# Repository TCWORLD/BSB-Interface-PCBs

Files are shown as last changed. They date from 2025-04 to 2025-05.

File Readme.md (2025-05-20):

# Boiler System Bus (BSB) Interface PCB Designs

This repository contains a series of PCB designs used to interface between the Boiler System Bus (BSB) of certain heating systems and network interfaces.

## MCU Software

The hardware is compatible with the ESP32 software implementations from [fredlcore/BSB-LAN](https://github.com/fredlcore/BSB-LAN/). 
Note: This repo is **not affiliated** with said project in any way - support queries for these PCB designs should **not** be directed to that project.

## Hardware

The hardware is based around an ESP32 controller, with either PoE LAN or WiFi network connectivity.

The PCBs have been laid out using Eagle PCB V6.6 and use predominantly surface mount components to make machine assembly easier. Parts used are all available for assembly in JLCPCBs parts catalogue.

A library file containing all parts used is included in the repository.

CAM files are included for generating 2-Layer and 4-Layer Gerber files using a naming scheme compatible with JLCs upload.

The repository contains a ULP file that can be run to generate the CPL/BOM files for upload to JLC. 
The `LCSC_PART` and `JLC_X/Y/ROTATION` attributes have been added for each component to simplify generation of the assembly spreadsheets required by JLC. If changing the PCB designs, ensure these attributes are updated as necessary.

### BSB-to-PoELaN for DIN Mount enclosure

A full implementation including ESP32 WROOM-32UE controller, PoE Ethernet power and networking, and USB programming and SD card interfaces.

This design has been built and is fully functional. It requires the following settings in the BSB-LAN software:

* In `BSB_LAN_config.h`: Configure the following setting:
    ```
    byte bus_pins[2] = {36,4};
    ```
* In `BSB_LAN_custom_setup.h`: Add the following code:
    ```
    // Set TX Enable pin to output and set high now that the system is initialised and the
    // TX line is being driven correctly
    pinMode(32, OUTPUT);
    digitalWrite(32, HIGH);
    ```

The board and components have been designed for use with JLCPCBs economic assembly process. 

The form factor of the board has been designed to fit in a Camdenboss CNMB/3/KIT DIN mount enclosure to provide a tidy fully enclosed solution.

### BSB-to-UEXT Daughter Board *UNTESTED*

Designed to work with the ESP32-POE-ISO controller from Olimex, connecting vial the UEXT headers.

The PCB schematic is simply based on the design found at in the GitHub repository [fredlcore/BSB-LAN](https://github.com/fredlcore/BSB-LAN/tree/master/BSB_LAN/schematics).

There are some slight adaptions to provide ESD protection for the isolated B2B interface and designed to be surface-mount machine for machine assembly. 

### BSB-to-WiFi for DIN Mount enclosure *UNTESTED*

A full implementation including ESP32 WROOM-32E controller, WiFi-only networking (PCB antenna, footprint compatible with external antenna), and USB programming and SD card interfaces.
This variant omits the LAN components to reduce the number of parts and make the board cheaper to manufacture. 
Power is supplied from either a 12V screw terminal (isolated through DC/DC for safety), or powered by the USB programming port.

The board and components have been designed for use with JLCPCBs economic assembly process. 

The form factor of the board has been designed to fit in a Camdenboss CNMB/2/KIT DIN mount enclosure to provide a tidy fully enclosed solution.

---

<br />This work is licensed under a <a rel="license" href="http://creativecommons.org/licenses/by-nc-sa/4.0/">Creative Commons Attribution-NonCommercial-ShareAlike 4.0 International License</a>.

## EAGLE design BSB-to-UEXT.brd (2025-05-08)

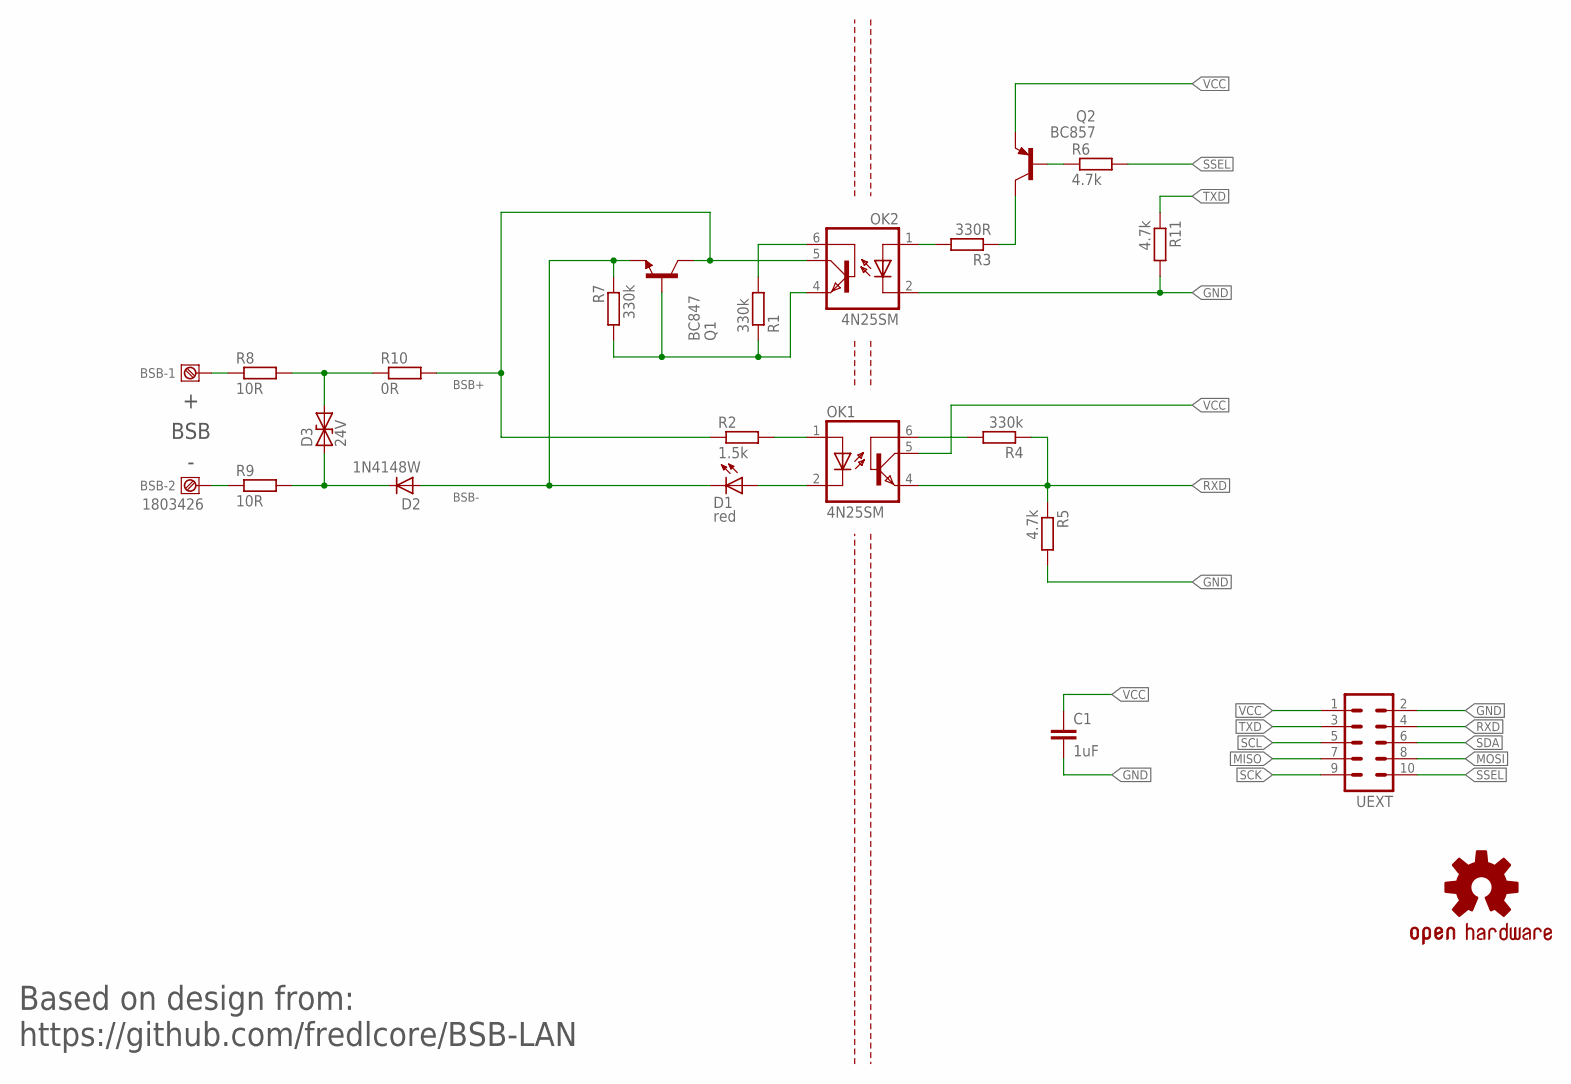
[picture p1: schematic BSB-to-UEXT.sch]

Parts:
BSB: 1803426; LCSC_PART C480514
C1: 1uF; C0805; LCSC_PART C28323
D1: red; CHIPLED_0805; LCSC_PART C84256
D2: 1N4148W; SOD123; LCSC_PART C81598
D3: 24V; SMBG; LCSC_PART C83268
OK1, OK2: 4N25SM; DIL6-SMD; LCSC_PART C258246
Q1: BC847; SOT23; LCSC_PART C130417
Q2: BC857; SOT23-BEC; LCSC_PART C426782
R1, R4, R7: 330k; R0805; LCSC_PART C17629
R2: 1.5k; R0805; LCSC_PART C4310
R3: 330R; R0805; LCSC_PART C17630
R5, R6, R11: 4.7k; R0805; LCSC_PART C17673
R8, R9: 10R; R1206; LCSC_PART C17903
R10: 0R; R1206L; LCSC_PART C17888
U$3: DNI; OSHW-LOGO-M
UEXT: ML10F

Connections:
BSB+: OK2.5 (COL), Q1.3 (C), R2.1, R10.2
BSB-: D1.C, D2.A, Q1.2 (E), R7.1
BSB-RX-A: OK1.1 (A), R2.2
BSB-RX-K: D1.A, OK1.2 (C)
BSB-TX-B: OK2.6 (BAS), R1.2
BSB-TX-E: OK2.4 (EMI), Q1.1 (B), R1.1, R7.2
CON-BSB+: BSB.1, R8.1
CON-BSB-: BSB.2, R9.1
GND: C1.2, OK2.2 (C), R5.2, R11.2, UEXT.2
MISO: UEXT.7
MOSI: UEXT.8
RXD: OK1.4 (EMI), R4.1, R5.1, UEXT.4
RXD-B: OK1.6 (BAS), R4.2
SCK: UEXT.9
SCL: UEXT.5
SDA: UEXT.6
SSEL: R6.2, UEXT.10
TVS-BSB+: D3.2, R8.2, R10.1
TVS-BSB-: D2.C, D3.1, R9.2
TXD: R11.1, UEXT.3
TXD-A: OK2.1 (A), R3.2
TXD-B: Q2.B, R6.1
TXD-C: Q2.C, R3.1
VCC: C1.1, OK1.5 (COL), Q2.E, UEXT.1

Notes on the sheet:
+ BSB -
Based on design from: https://github.com/fredlcore/BSB-LAN

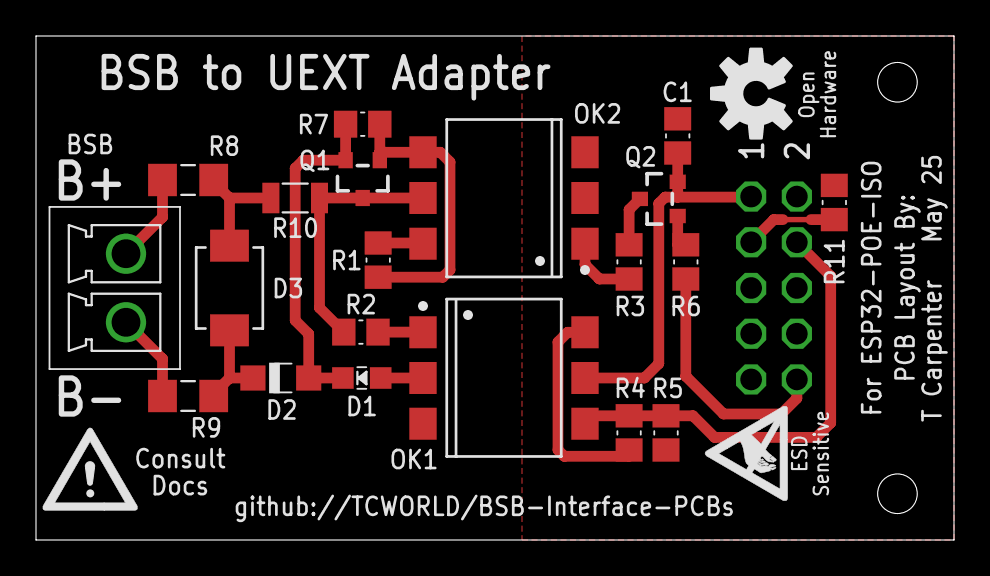
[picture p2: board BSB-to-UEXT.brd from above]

Board: 2 copper layers, 51.0 x 28.0 mm, 24 parts (1 on the bottom side), 19 nets.

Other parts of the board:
U$1: WARN-TINY
U$2: ESD-TINY

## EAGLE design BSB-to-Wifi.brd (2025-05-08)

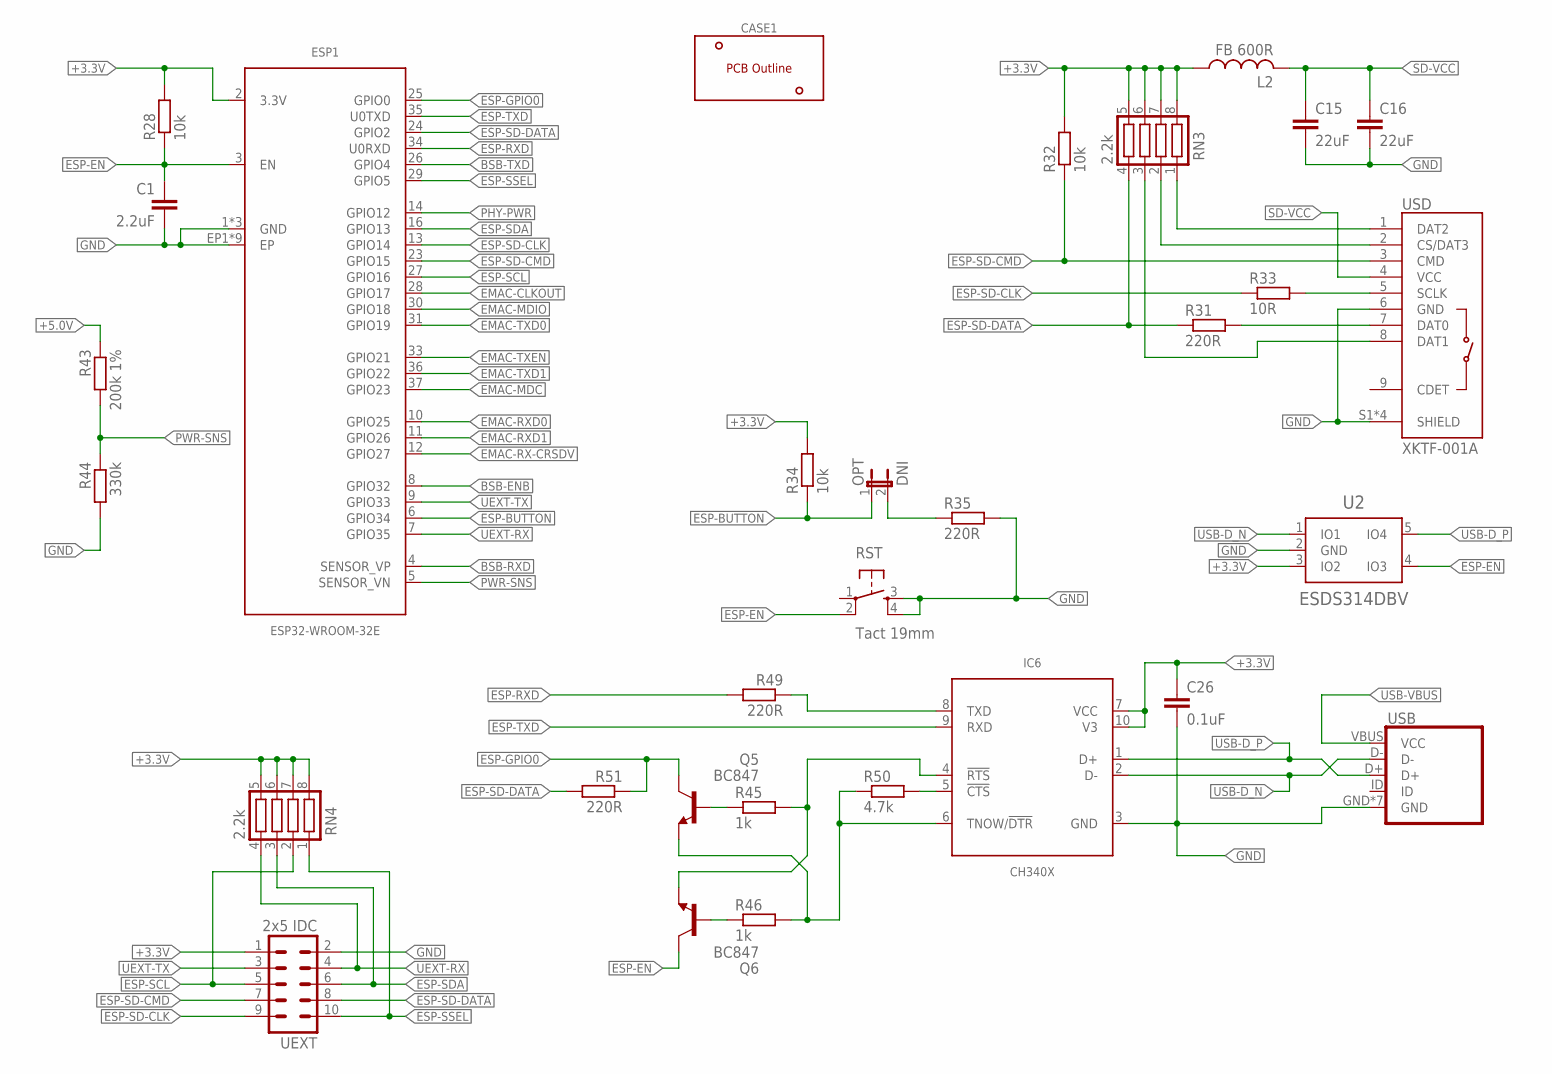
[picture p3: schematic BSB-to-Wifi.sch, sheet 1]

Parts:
C1: 2.2uF; C0603; LCSC_PART C23630
C15, C16: 22uF; C0805L; LCSC_PART C45783
C26: 0.1uF; C0402; LCSC_PART C1525
CASE1: DNI; CNMB/2-
ESP1: ESP32-WROOM-32E
IC6: CH340X; MSOP10
L2: FB 600R; L2010; LCSC_PART C1017
OPT: DNI; 1X02
Q5: BC847; SOT23; LCSC_PART C130417
Q6: BC847; SOT23
R28, R32, R34: 10k; R0402; LCSC_PART C25744
R31, R35, R49, R51: 220R; R0402; LCSC_PART C25091
R33: 10R; R0603L; LCSC_PART C22859
R43: 200k 1%; R0402; LCSC_PART C25764
R44: 330k; R0603L; LCSC_PART C23137
R45, R46: 1k; R0402; LCSC_PART C11702
R50: 4.7k; R0402; LCSC_PART C25900
RN3, RN4: 2.2k; CTS742C083; LCSC_PART C414564
RST: Tact 19mm; TACTILE_SWITCH; LCSC_PART C2837529
U2: ESDS314DBV; DBV0005A-SOT23
UEXT: 2x5 IDC; ML10
USB: ZX62-B-5PA(33); USB-MICROB
USD: XKTF-001A; MICRO-SD

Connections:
+3.3V: C26.1, ESP1.2 (3.3V), IC6.7 (VCC), IC6.10 (V3), L2.1, R28.2, R32.2, R34.2, RN3.5, RN3.6, RN3.7, RN3.8, RN4.5, RN4.6, RN4.7, RN4.8, U2.3 (IO2), UEXT.1; also elsewhere on the board
+5.0V: R43.1; also elsewhere on the board
BSB-ENB: ESP1.8 (GPIO32); also elsewhere on the board
BSB-RXD: ESP1.4 (SENSOR_VP); also elsewhere on the board
BSB-TXD: ESP1.26 (GPIO4); also elsewhere on the board
CH340-!CTS: IC6.5 (!CTS), R50.2
CH340-!DTR: IC6.6 (TNOW/!DTR), Q5.2 (E), R46.2, R50.1
CH340-!RTS: IC6.4 (!RTS), Q6.2 (E), R45.2
CH340-TXD: IC6.8 (TXD), R49.1
EMAC-CLKOUT: ESP1.28 (GPIO17)
EMAC-MDC: ESP1.37 (GPIO23)
EMAC-MDIO: ESP1.30 (GPIO18)
EMAC-RX-CRSDV: ESP1.12 (GPIO27)
EMAC-RXD0: ESP1.10 (GPIO25)
EMAC-RXD1: ESP1.11 (GPIO26)
EMAC-TXD0: ESP1.31 (GPIO19)
EMAC-TXD1: ESP1.36 (GPIO22)
EMAC-TXEN: ESP1.33 (GPIO21)
ESP-BUTTON: ESP1.6 (GPIO34), OPT.1, R34.1
ESP-BUTTON-R: OPT.2, R35.1
ESP-EN: C1.1, ESP1.3 (EN), Q6.3 (C), R28.1, RST.2, U2.4 (IO3)
ESP-EN-OE: Q6.1 (B), R46.1
ESP-GPIO0: ESP1.25 (GPIO0), Q5.3 (C), R51.1
ESP-GPIO0-OE: Q5.1 (B), R45.1
ESP-RXD: ESP1.34 (U0RXD), R49.2
ESP-SCL: ESP1.27 (GPIO16), RN4.2, UEXT.5
ESP-SD-CLK: ESP1.13 (GPIO14), R33.1, UEXT.9
ESP-SD-CMD: ESP1.23 (GPIO15), R32.1, UEXT.7, USD.3 (CMD)
ESP-SD-DATA: ESP1.24 (GPIO2), R31.1, R51.2, RN3.4, UEXT.8
ESP-SDA: ESP1.16 (GPIO13), RN4.3, UEXT.6
ESP-SSEL: ESP1.29 (GPIO5), RN4.1, UEXT.10
ESP-TXD: ESP1.35 (U0TXD), IC6.9 (RXD)
GND: C1.2, C15.2, C16.2, C26.2, ESP1.1 (GND), ESP1.15 (GND), ESP1.38 (GND), ESP1.EP1 (EP), ESP1.EP2 (EP), ESP1.EP3 (EP), ESP1.EP4 (EP), ESP1.EP5 (EP), ESP1.EP6 (EP), ESP1.EP7 (EP), ESP1.EP8 (EP), ESP1.EP9 (EP), IC6.3 (GND), R35.2, R44.2, RST.3, RST.4, U2.2 (GND), UEXT.2, USB.GND, USB.MT1 (GND), USB.MT2 (GND), USB.MT3 (GND), USB.MT4 (GND), USB.MT5 (GND), USB.MT6 (GND), USD.6 (GND), USD.S1 (SHIELD), USD.S2 (SHIELD), USD.S3 (SHIELD), USD.S4 (SHIELD); also elsewhere on the board
PHY-PWR: ESP1.14 (GPIO12)
PWR-SNS: ESP1.5 (SENSOR_VN), R43.2, R44.1
SD-DAT0: R31.2, USD.7 (DAT0)
SD-DAT1: RN3.3, USD.8 (DAT1)
SD-DAT2: RN3.1, USD.1 (DAT2)
SD-DAT3: RN3.2, USD.2 (CS/DAT3)
SD-SCLK: R33.2, USD.5 (SCLK)
SD-VCC: C15.1, C16.1, L2.2, USD.4 (VCC)
UEXT-RX: ESP1.7 (GPIO35), RN4.4, UEXT.4
UEXT-TX: ESP1.9 (GPIO33), UEXT.3
USB-D_N: IC6.2 (D-), U2.1 (IO1), USB.D-
USB-D_P: IC6.1 (D+), U2.5 (IO4), USB.D+
USB-VBUS: USB.VBUS (VCC); also elsewhere on the board

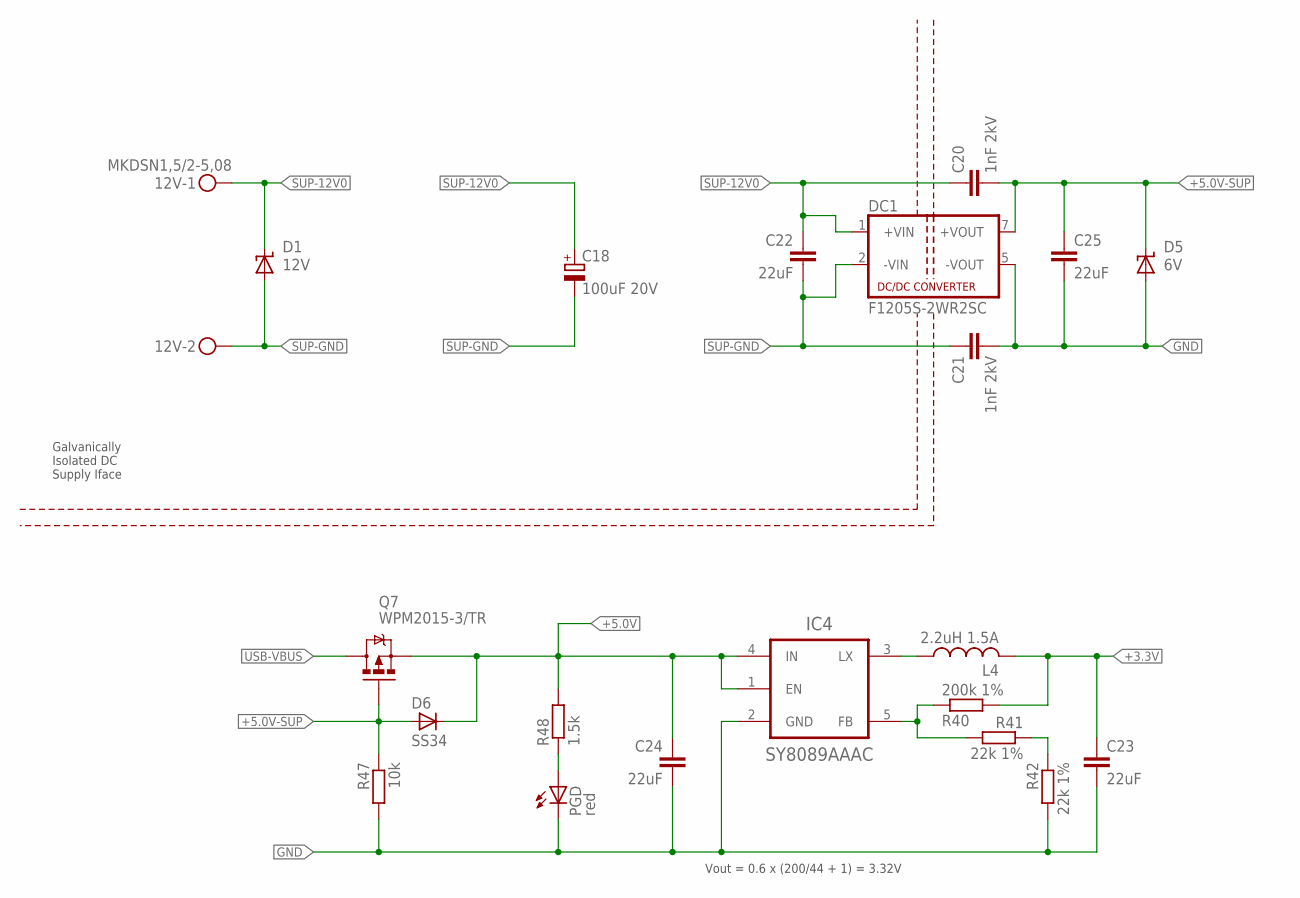
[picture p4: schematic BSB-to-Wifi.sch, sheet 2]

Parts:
12V: MKDSN1,5/2-5,08; MKDSN1_5-2-5_08
C18: 100uF 20V; SMC_D; LCSC_PART C7224
C20, C21: 1nF 2kV; C1206L; LCSC_PART C9196
C22, C23, C24, C25: 22uF; C0805; LCSC_PART C45783
D1: 12V; SMA; LCSC_PART C148213
D5: 6V; SMA; LCSC_PART C223993
D6: SS34; SMA; LCSC_PART C8678
DC1: F1205S-2WR2SC; SIP7-N
IC4: SY8089AAAC; DBV0005A-SOT23
L4: 2.2uH 1.5A; L4040P; LCSC_PART C135262
PGD: red; CHIP-LED0603; LCSC_PART C2286
Q7: WPM2015-3/TR; SOT23
R40: 200k 1%; R0402; LCSC_PART C25764
R41, R42: 22k 1%; R0402; LCSC_PART C25768
R47: 10k; R0402; LCSC_PART C25744
R48: 1.5k; R0603; LCSC_PART C22843

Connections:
3V3-FB: IC4.5 (FB), R40.1, R41.2
3V3-FB-RB: R41.1, R42.1
3V3-LX: IC4.3 (LX), L4.1
+3.3V: C23.1, L4.2, R40.2; also elsewhere on the board
+5.0V: C24.1, D6.C, IC4.1 (EN), IC4.4 (IN), Q7.2 (S), R48.2; also elsewhere on the board
+5.0V-SUP: C20.2, C25.1, D5.C, D6.A, DC1.7 (+VOUT), Q7.1 (G), R47.1
GND: C21.2, C23.2, C24.2, C25.2, D5.A, DC1.5 (-VOUT), IC4.2 (GND), PGD.C, R42.2, R47.2; also elsewhere on the board
PWR-LED: PGD.A, R48.1
SUP-12V0: 12V.1, C18.+, C20.1, C22.1, D1.C, DC1.1 (+VIN)
SUP-GND: 12V.2, C18.-, C21.1, C22.2, D1.A, DC1.2 (-VIN)
USB-VBUS: Q7.3 (D); also elsewhere on the board

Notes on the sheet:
Galvanically Isolated DC Supply Iface
Vout = 0.6 x (200/44 + 1) = 3.32V

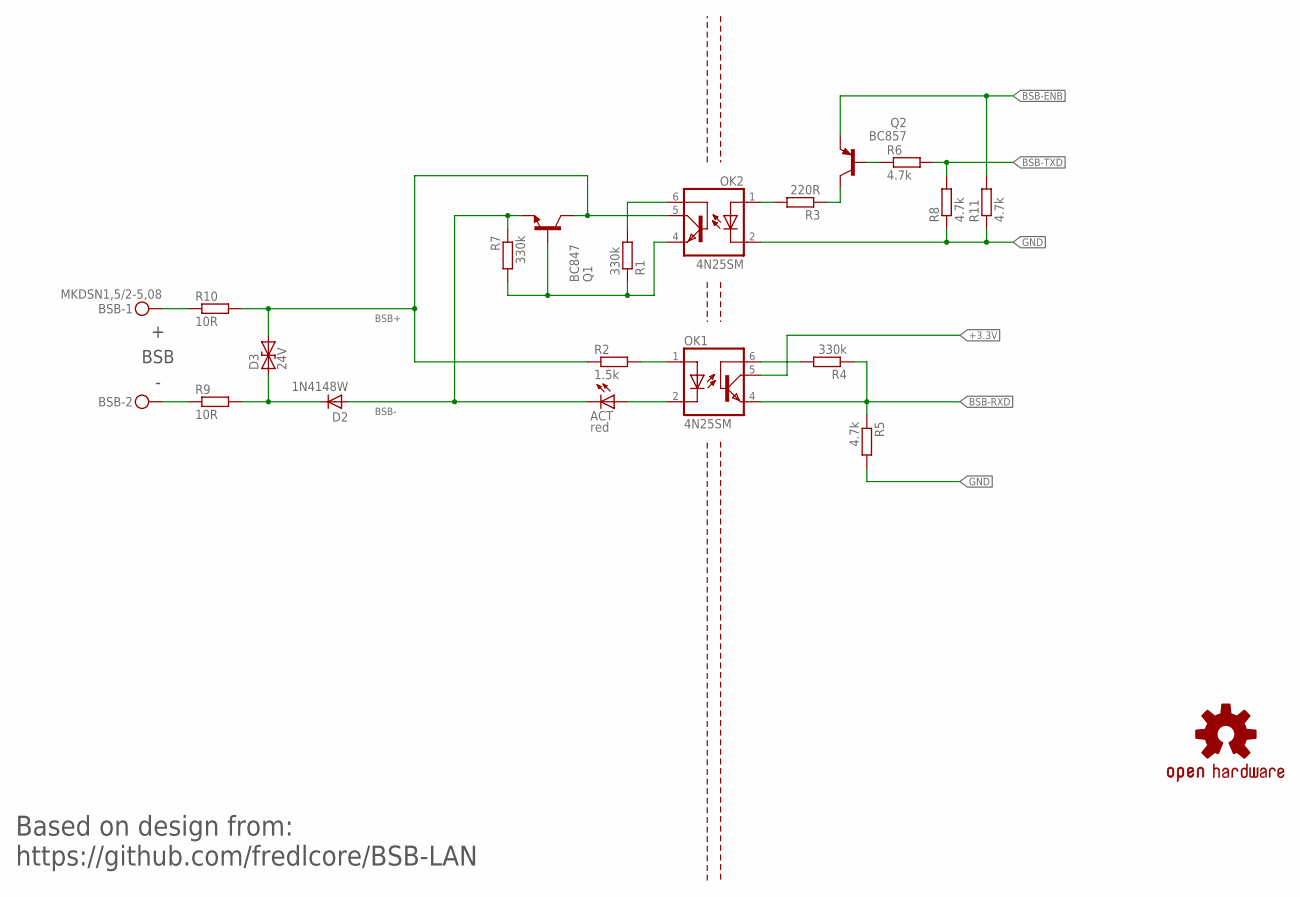
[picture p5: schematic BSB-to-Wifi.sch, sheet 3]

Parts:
ACT: red; CHIP-LED0603; LCSC_PART C2286
BSB: MKDSN1,5/2-5,08; MKDSN1_5-2-5_08
D2: 1N4148W; SOD123; LCSC_PART C81598
D3: 24V; SMBG; LCSC_PART C83268
OK1, OK2: 4N25SM; DIL6-SMD; LCSC_PART C258246
Q1: BC847; SOT23; LCSC_PART C130417
Q2: BC857; SOT23-BEC; LCSC_PART C426782
R1, R4, R7: 330k; R0603; LCSC_PART C23137
R2: 1.5k; R0603; LCSC_PART C22843
R3: 220R; R0402; LCSC_PART C25091
R5, R6, R8, R11: 4.7k; R0402; LCSC_PART C25900
R9, R10: 10R; R0603; LCSC_PART C22859
U$3: DNI; OSHW-LOGO-M

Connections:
+3.3V: OK1.5 (COL); also elsewhere on the board
BSB+: D3.2, OK2.5 (COL), Q1.3 (C), R2.1, R10.2
BSB-: ACT.C, D2.A, Q1.2 (E), R7.1
BSB-ENB: Q2.E, R11.2; also elsewhere on the board
BSB-RX-A: OK1.1 (A), R2.2
BSB-RX-K: ACT.A, OK1.2 (C)
BSB-RXD: OK1.4 (EMI), R4.1, R5.1; also elsewhere on the board
BSB-TX-B: OK2.6 (BAS), R1.2
BSB-TX-E: OK2.4 (EMI), Q1.1 (B), R1.1, R7.2
BSB-TXD: R6.2, R8.2; also elsewhere on the board
CON-BSB+: BSB.1, R10.1
CON-BSB-: BSB.2, R9.1
GND: OK2.2 (C), R5.2, R8.1, R11.1; also elsewhere on the board
RXD-B: OK1.6 (BAS), R4.2
TVS-BSB-: D2.C, D3.1, R9.2
TXD-A: OK2.1 (A), R3.2
TXD-B: Q2.B, R6.1
TXD-C: Q2.C, R3.1

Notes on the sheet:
+ BSB -
Based on design from: https://github.com/fredlcore/BSB-LAN

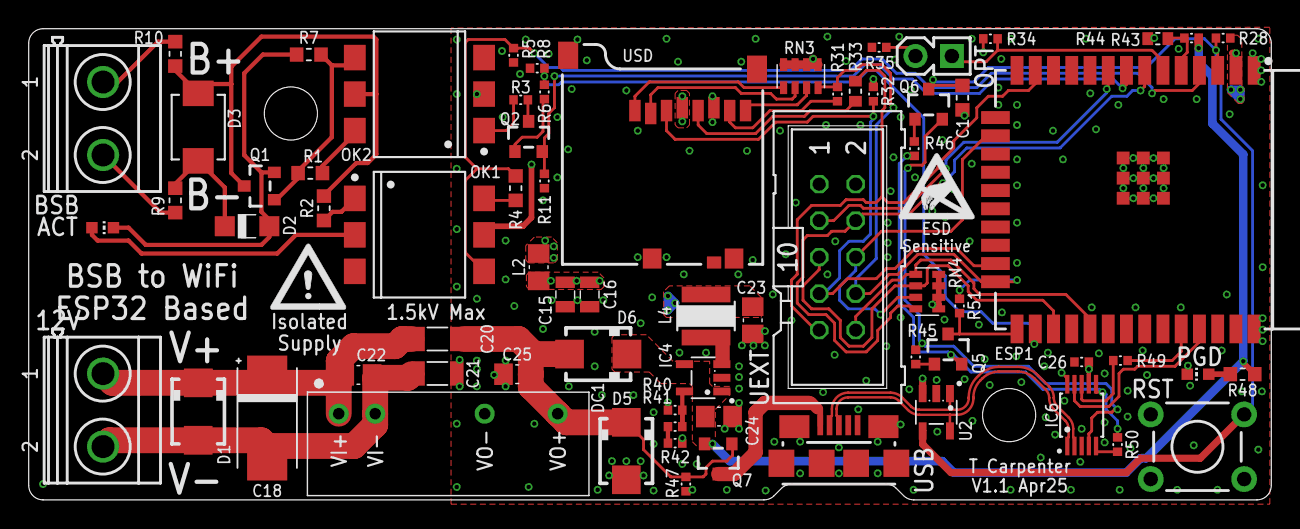
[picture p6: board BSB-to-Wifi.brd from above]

Board: 4 copper layers, 86.5 x 32.8 mm, 74 parts (1 on the bottom side), 56 nets.

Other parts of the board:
U$1: WARN-TINY
U$2: ESD-TINY

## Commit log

2025-02-23 Implement First Draft Schematic/PCB Design
    Exported used library subset also included.
    [BSB-LAN.brd, BSB-LAN.sch]
2025-03-01 Add OSHW Logo
    [BSB-LAN.brd, BSB-LAN.sch]
2025-03-07 Add More Parts to BSB-LAN Library
    This includes basically sufficient parts to build an ESP32 dev kit.
2025-03-07 Begin designing full BSB-LAN + ESP32 Board
    Rather than a module that plugs onto an Olimex dev kit, this is a fully integrated board which includes the ESP32, PoE Ethernet, USB programming Iface. and BSB interface.
    The board is designed to fit into a DIN rail enclosure (Camdenboss CNMB/2).
    [BSB-LAN-Full.brd, BSB-LAN-Full.sch]
2025-03-07 Correct uSD Card Footprint
    Add keepout zone for SD card
2025-03-07 Route LAN8710A connections on full PCB
    [BSB-LAN-Full.brd, BSB-LAN-Full.sch]
2025-03-07 Add Keep-out to DIN enclosure footprint
    On the rear of the board, add a keep-out zone where the plastic support frame is located.
2025-03-07 Finish Routing Full Board
    Route the remaining BSB components, and also fix arrangement of parts on rear of the board which were encroaching the DIN frame keep-out.
    [BSB-LAN-Full.brd, BSB-LAN-Full.sch]
2025-03-07 Improve EMAC Clock Routing
    Ensure contiguous ground plane underneath as it transitions across the top layer.
    [BSB-LAN-Full.brd]
2025-03-07 Fix Silk
    [BSB-LAN-Full.brd]
2025-03-07 Rename Connector Footprint
    Remove special characters
    [BSB-LAN-Full.brd, BSB-LAN-Full.sch]
2025-03-08 Fix USB Position and Pinout UEXT 3/4
    1. Move the microUSB port inward so that it doesn't foul the enclosure.
    2. Pinout UEXT 3/4 to the spare GPIO pins 32/33. The correct two pins are in use by the BSB interface so they were previously left unconnected on UEXT, but we might as well have other GPIOs connected so we have a fully populated expansion header.
    [BSB-LAN-Full.brd, BSB-LAN-Full.sch]
2025-03-08 Assign JLC Part Numbers
    Minor adaptions to available passive parts and packages and now all parts are available in JLCs inventory. LCSC_PART attributes have been applied to aid in BoM creation.
    Additionally add extra ESD protection for USB port.
    [BSB-LAN-Full.brd, BSB-LAN-Full.sch]
2025-03-08 Begin optimising for assembly cost
    Trying to reduce the number of different components, as well as instances where the same component is used on two sides of the board (incurs double assembly setup fee).
    [BSB-LAN-Full.brd, BSB-LAN-Full.sch]
2025-03-08 Move LAN IC to Top Side
    With LAN IC on the top side, the board could be manufactered with only the top-side components populated, and with the exception of the uSD card all the bottom side parts are then relatively easy to 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
    [BSB-LAN-Full.brd, BSB-LAN-Full.sch]
2025-03-08 Correct CNMB Footprint Keepout
    The zone was measured wrong from the model. Need the backside components to be further from the edge. Fix the board layout to achieve this.
    [BSB-LAN-Full.brd, BSB-LAN-Full.sch]
2025-03-09 Add CNMB/3 Footprint and Update Libs
    Add footprint for the next size up enclosure.
    [BSB-LAN-Full.brd, BSB-LAN-Full.sch]
2025-03-09 Route Single Sided Assembly Version
    Create a version of the full design that uses the wider CNMB/3/KIT enclosure. This gives enough space to place all components on the top layer which should significantly reduce assembly cost.
    [BSB-LAN-Full-SS.brd, BSB-LAN-Full-SS.sch]
2025-03-09 Add CAM and ULP Helper Files
    For generating Gerber and BOM files.
2025-03-09 Fix RJ45 Position on Full-SS Board
    To ensure it's pins don't foul the PCB keepout zone.
    [BSB-LAN-Full-SS.brd]
2025-03-09 Correct PoE IC Part Number
    The LCSC_PART selected was the TPS2376DDA but the schematic value was TPS2375D, This actually has a slightly different footprint - the DDA has a thermal pad.
    Update to account for the change.
    [BSB-LAN-Full-SS.brd, BSB-LAN-Full-SS.sch, BSB-LAN-Full.brd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]
2025-03-09 Correct Component Rotation Values in JLC CPL
    Add rotation correction factors to parts which import in the wrong orientation.
    [BSB-LAN-Full-SS.brd, BSB-LAN-Full-SS.sch, BSB-LAN-Full.brd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]
2025-03-09 Reduce P1 Dot Side for DCDC
    Doesn't need to be 1mm!
2025-03-09 Change Stackup to JLC Default 4L
    Use the default stack-up using 7628 to allow the use of Economic assembly. Update trace widths of diff pairs accordingly.
    [BSB-LAN-Full-SS.brd, BSB-LAN-Full-SS.sch, BSB-LAN-Full.brd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]
2025-03-10 Fix CNMB/3 Terminal Positions
    And realign PCB components to the new coordinates. This is based on measurements of the 3D model in Solidworks.
    The ethernet connector has also been realigned to be central within three terminal blocks to make it easier to cut out its opening,
    [BSB-LAN-Full-SS.brd, BSB-LAN-Full-SS.sch]
2025-03-11 Add Missing Pull-Up Resistors on I2C
    [BSB-LAN-Full-SS.brd, BSB-LAN-Full-SS.sch, BSB-LAN-Full.brd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]
2025-03-12 Correct Pinout of DC-DC Converter
    Not sure quite how I messed up the pin assignments that badly!
    [BSB-LAN-Full-SS.brd, BSB-LAN-Full-SS.sch, BSB-LAN-Full.brd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]
2025-03-12 Correct LCSC_PART Attributes
    The power sense divider values were changed, but the attributes didn't get updated.
    [BSB-LAN-Full-SS.brd, BSB-LAN-Full-SS.sch, BSB-LAN-Full.brd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]
2025-03-12 Correct X-Y Offsets on some components for JLC CPL
    Four of the part origins in the design didn't match with the JLC CPL processor origins. Add extra attributes and modify ULP script to account for this.
    [BSB-LAN-Full-SS.brd, BSB-LAN-Full-SS.sch, BSB-LAN-Full.brd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]
2025-03-13 Create Wi-Fi Only Variant
    All PoE and Ethernet circuitry removed to make a lower cost more compact unit that uses Wi-Fi for comms.
    Runs from either a 12V supply or USB. The 12V supply is through an isolated DC-DC so could be sourced from the RVS21
    [BSB-LAN-Full-Wifi.brd, BSB-LAN-Full-Wifi.sch]
2025-03-13 Update Libraries in basic BSB-LAN design
    Bring up to date with JLC export attributes.
    [BSB-LAN.brd, BSB-LAN.sch]
2025-03-13 Add missing pull-down to BSB-LAN adapter
    4.7k on the TX pin to assist with boot issues on the Olimex dev kit.
    [BSB-LAN.brd, BSB-LAN.sch]
2025-03-17 Add Missing LCSC_PART Attributes on BSB-LAN-Full-Wifi
    Missing TVS and DC-DC JLC assembly part numbers.
    [BSB-LAN-Full-Wifi.brd, BSB-LAN-Full-Wifi.sch]
2025-03-17 Reduce Wifi BoM Complexity
    There were some weird values left that were holdovers from the LAN board where they were used elsewhere.
    [BSB-LAN-Full-SS.brd, BSB-LAN-Full-SS.sch, BSB-LAN-Full-Wifi.brd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]
2025-03-25 Annotate Alternate Parts for Full S-S design
    Some parts can have alternative compatible PNs.
    [BSB-LAN-Full-SS.sch]
2025-04-14 Library Improvements
    1. Add JLC X-Y correction to ESP32 w/ external antenna, and the right angled reset switch.
    2. Fix hole positions for SIP7 DC-DC package.
    3. Correct hole sizes for Camdenboss enclosures. Should be 6-32 UNC not M3. Restrict is set for smaller button head screws.
2025-04-14 Correct ESP32 Prog Control + Update Libraries
    1. Correct the control of automatic bootloader entry by adding missing resistor from GPIO2 to GPIO0.
    2. Update libraries and fix layout to account for changes.
    3. Change the LAN versions of the boards to use the ESP32 with external antenna. If the PCB antenna is used then it is not possible to get the PCB into the enclosure because components stick out on both ends!
    [BSB-LAN-Full-SS.brd, BSB-LAN-Full-SS.sch, BSB-LAN-Full-Wifi.brd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]
2025-04-17 Smaller Reset Switch on BSB-LAN-Full
    Use a smaller reset switch so that it is mechanically possible to fit the board into its enclosure - we can't have components hanging over both ends of the board otherwise it won't fit into the case.
    [BSB-LAN-Full.brd, BSB-LAN-Full.sch]
2025-04-17 Tweak LAN Connector Location on BSB-LAN-Full-SS
    Improve shield ground plane connectivity.
    [BSB-LAN-Full-SS.brd]
2025-04-19 Adjust Silkscreen
    [BSB-LAN-Full-SS.brd, BSB-LAN-Full-Wifi.brd, BSB-LAN-Full.brd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]
2025-04-19 Rearrange Repository Files
    [BSB-to-PoELAN-Compact.brd, BSB-to-PoELAN-Compact.sch, BSB-to-PoELAN.brd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]
2025-05-08 Add BSB Tx Enable Control
    Move the UEXT RX on GPIO35 (input only), and use GPIO32 instead for controlling whether the BSB-TXD pin can drive the optocoupler. This basically replaces the +3.3V connection on the emitter of the invert transistor.
    What this means is that when the ESP32 has not yet booted, or if it crashes along the way, the BSB bus is not being driven into TX mode by the pull-down bootstrap resistor. This should stop BSB bus short detection errors when the unit is powered off or has not yet started up.
    This will require custom code in the BSB firmware setup (BSB_LAN_custom_setup.h) to configure the enable pin to be an output and driven high. Until that is done the BSB bus remai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
    [BSB-to-PoELAN.brd, BSB-to-PoELAN.sch, BSB-to-Wifi.brd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]
2025-05-08 Change BSB-to-UEXT Tx Pin Assignment
    Follow the BSB-LAN repo in moving TX onto the UEXT-SSEL pin instead of the UEXT-TX pin. This is done to avoid issues with the TX pin needing to be pulled low during the boot phase, but that in turn would "short" out the BSB bus until everything is booted up.
    [BSB-to-UEXT.brd, BSB-to-UEXT.sch]
2025-05-20 Update Readme.md
    The `BSB-to-PoELAN` board has now been testing and works correctly.
    Add the required config settings into the readme.
